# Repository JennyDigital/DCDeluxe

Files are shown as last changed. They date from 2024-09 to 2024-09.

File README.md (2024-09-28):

## It's a door chime board, but programmable.

It can literally sound however you want, but the source-code (unfinished) is provided to get you up-and-runninng.

Have you wondered why there's four DIP switches?.. Coming soon:  A melody playing feature!

...also, let me apologise for the ugly appearance of the CubeMX generated portions of the code, the tool generates ugly code and re-generates it with each re-generated change.  You can tidy it, but it'll just go back to ugly each time.

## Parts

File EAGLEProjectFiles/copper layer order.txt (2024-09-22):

Order of copper layers.
=======================

cmp is the top copper layer.
L2 is the upper inner layer.
L15 is he lower inner layer.
sol is the bottom layer.

Also, the PCB is designed with two prepegs separated by one core, thus placing cmp and L2 very close to each other.  This is inentional.

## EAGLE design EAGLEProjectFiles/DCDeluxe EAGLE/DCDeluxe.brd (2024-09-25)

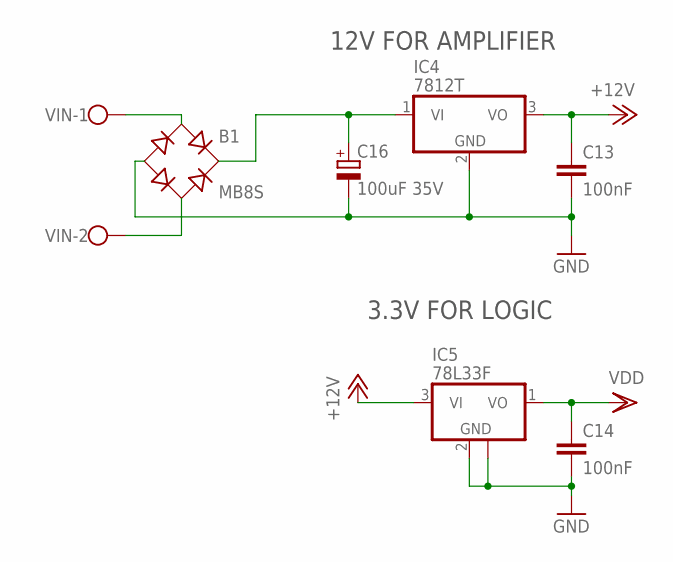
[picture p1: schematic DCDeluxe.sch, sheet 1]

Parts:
B1: MB8S; SOIC-4
C13, C14: 100nF; C0603
C16: 100uF 35V; 153CLV-0807
IC4: 7812T; TO220H
IC5: 78L33F; SOT89
VIN: W237-102

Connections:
+12V: C13.1, IC4.3 (VO), IC5.3 (VI); also elsewhere on the board
GND: B1.-, C13.2, C14.2, C16.-, IC4.2 (GND), IC5.2 (GND), IC5.2@1 (GND); also elsewhere on the board
VDD: C14.1, IC5.1 (VO); also elsewhere on the board
VIN1: B1.~1 (AC1), VIN.1; also elsewhere on the board
VIN2: B1.~2 (AC2), VIN.2; also elsewhere on the board
VIN+: B1.+, C16.+, IC4.1 (VI)

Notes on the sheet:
12V FOR AMPLIFIER
3.3V FOR LOGIC

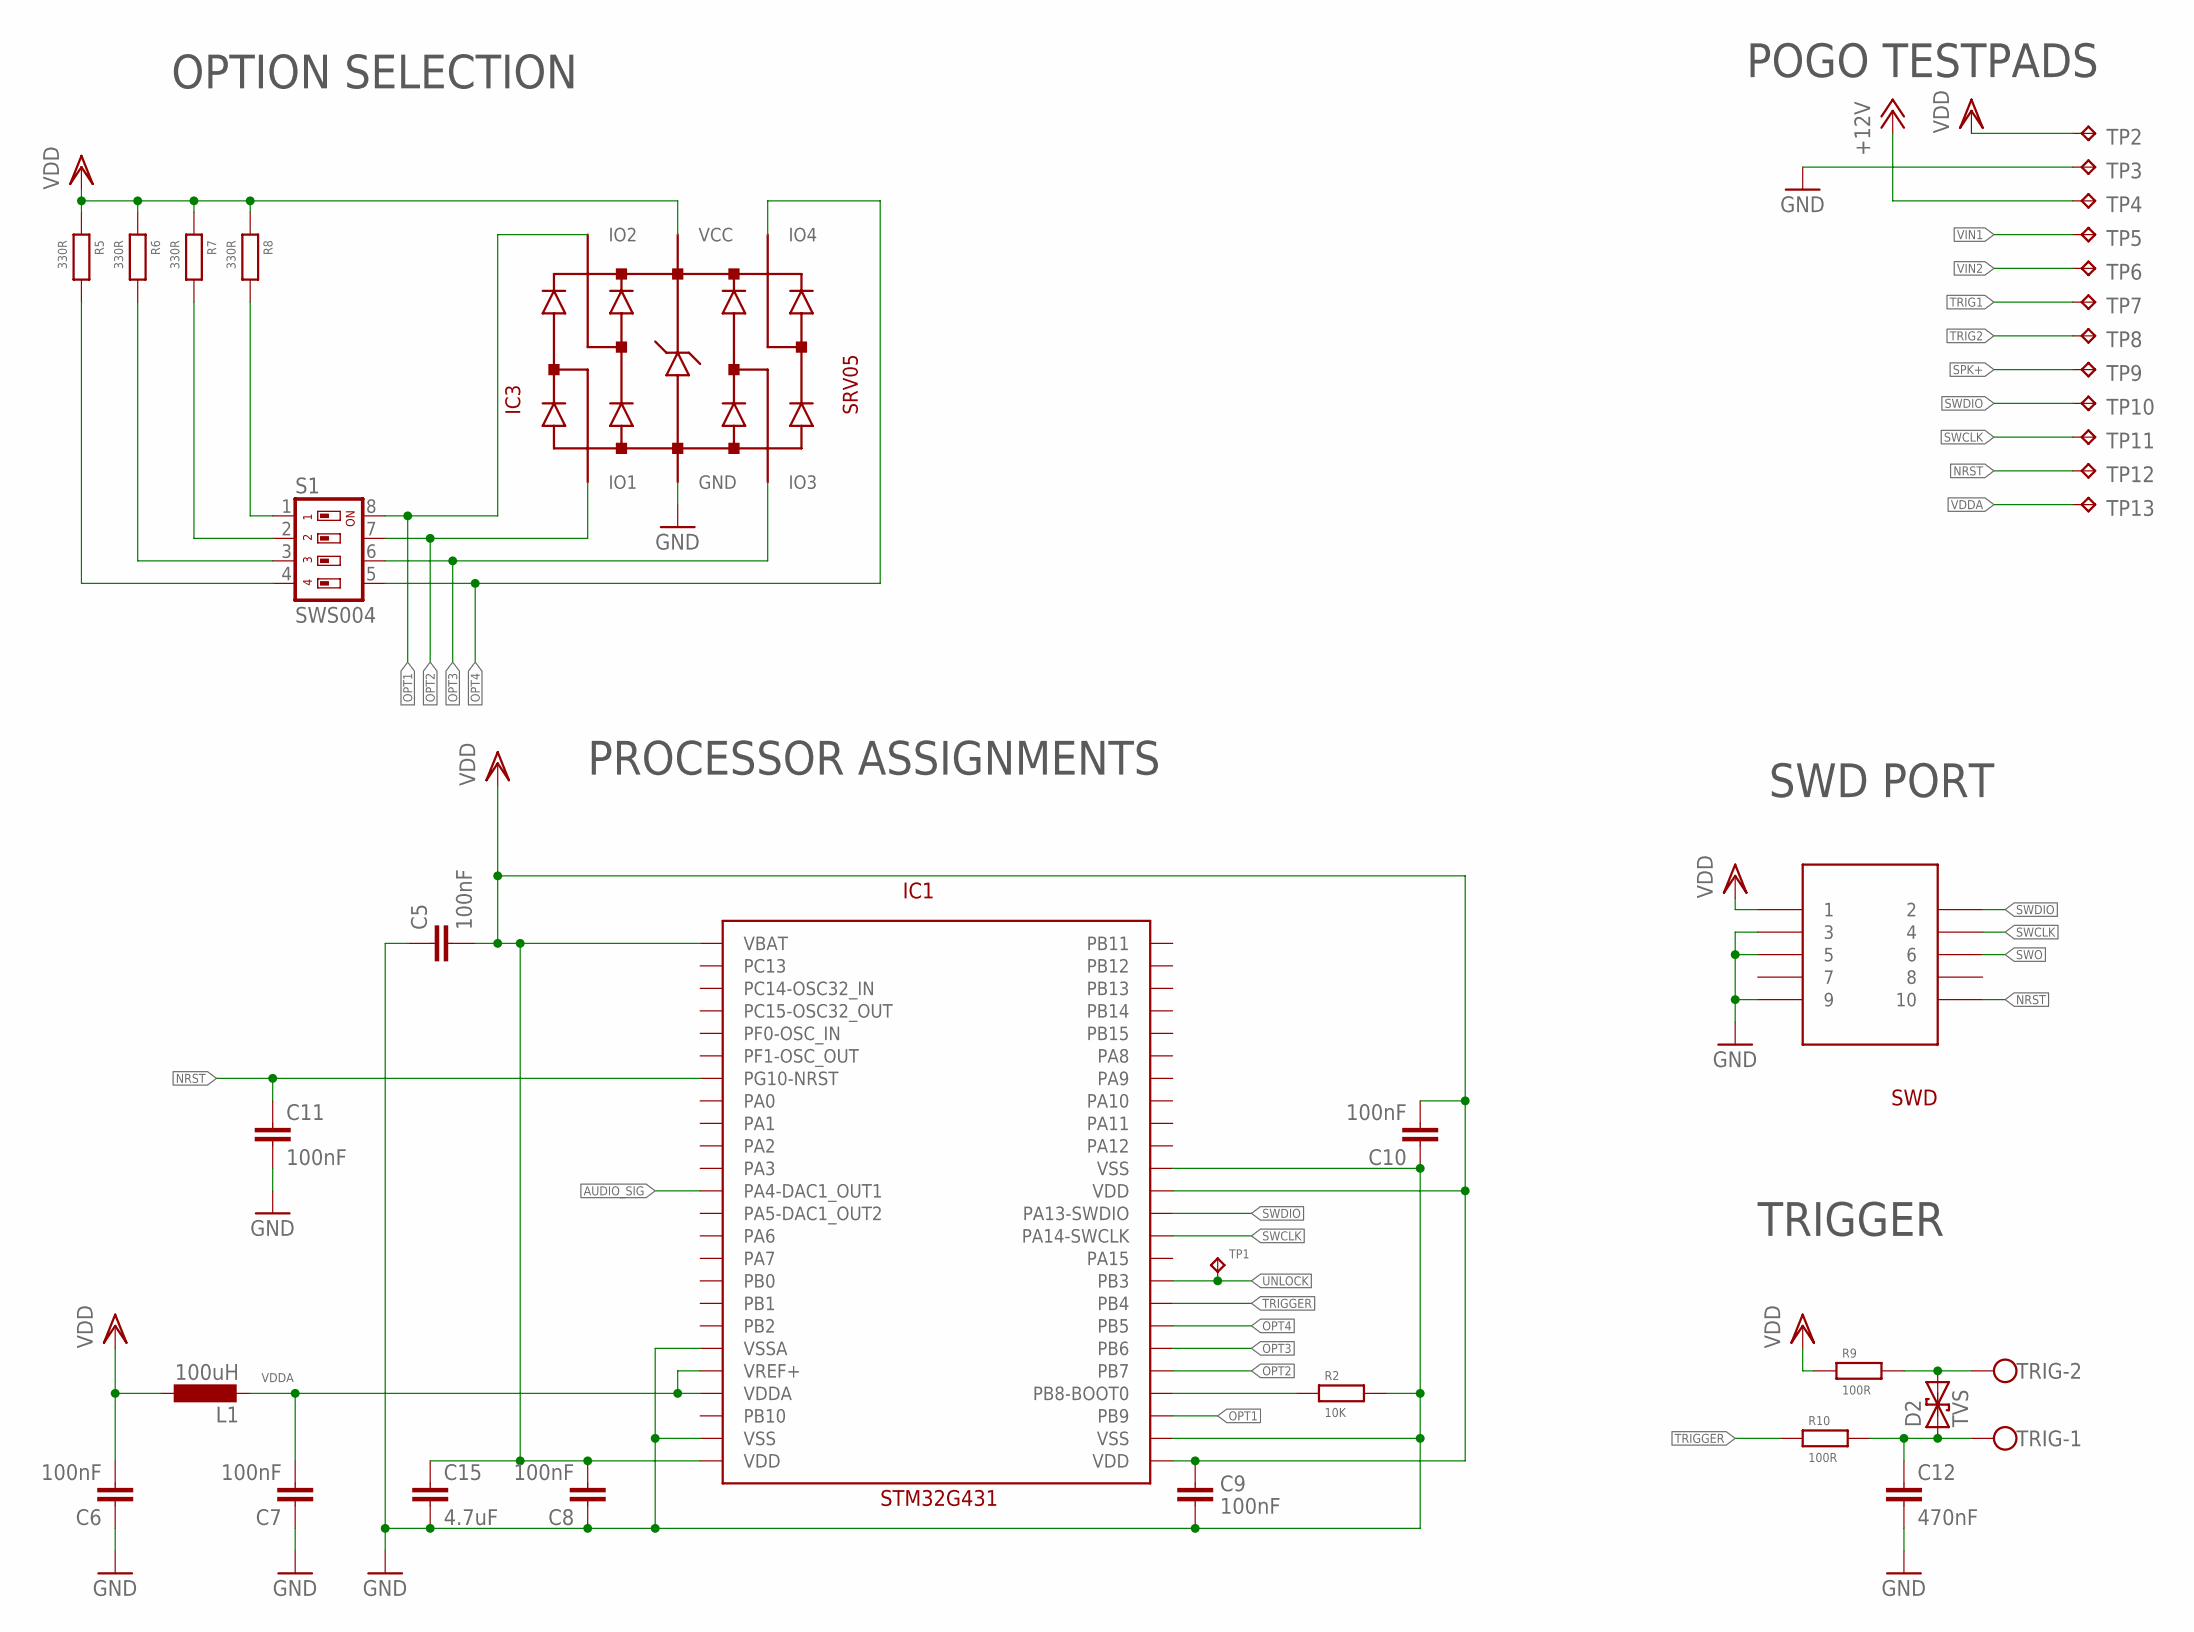
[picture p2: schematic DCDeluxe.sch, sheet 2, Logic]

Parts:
C5, C6, C7, C8, C9, C10, C11: 100nF; C0603
C12: 470nF; C0603
C15: 4.7uF; C0603
D2: TVS; SMA-DIODE
IC1: STM32G431; TQFP48
IC3: SRV05; TSOP-6
L1: 100uH; L3225M
R2: 10K; R0603
R5, R6, R7, R8: 330R; R0603
R9, R10: 100R; R0603
S1: SWS004; SMS-004
SWD: FTSH-105-01; FTSH-105-01-XXX-DV-K
TP1: TPTP12R; TP12R
TP2, TP3, TP4, TP5, TP6, TP7, TP8, TP9, TP10, TP11, TP12, TP13: TPTP20R; TP20R
TRIG: W237-102

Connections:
+12V: TP4.TP; also elsewhere on the board
AUDIO_SIG: IC1.PA4-DAC1_OUT1; also elsewhere on the board
BOOT0: IC1.PB8-BOOT0, R2.1
GND: C5.1, C6.1, C7.1, C8.1, C9.1, C10.1, C11.2, C12.2, C15.2, IC1.VSS@23 (VSS), IC1.VSS@35 (VSS), IC1.VSS@47 (VSS), IC1.VSSA, IC3.GND, R2.2, SWD.3, SWD.5, SWD.9, TP3.TP; also elsewhere on the board
unnamed: R8.2, S1.1
unnamed: R7.2, S1.2
unnamed: R6.2, S1.3
unnamed: R5.2, S1.4
NRST: C11.1, IC1.PG10-NRST, SWD.10, TP12.TP
OPT1: IC1.PB9, IC3.IO2, S1.8
OPT2: IC1.PB7, IC3.IO1, S1.7
OPT3: IC1.PB6, IC3.IO3, S1.6
OPT4: IC1.PB5, IC3.IO4, S1.5
SPK+: TP9.TP; also elsewhere on the board
SWCLK: IC1.PA14-SWCLK, SWD.4, TP11.TP
SWDIO: IC1.PA13-SWDIO, SWD.2, TP10.TP
SWO: SWD.6
TRIG1: C12.1, D2.A (1), R10.2, TP7.TP, TRIG.1
TRIG2: D2.C (2), R9.2, TP8.TP, TRIG.2
TRIGGER: IC1.PB4, R10.1
UNLOCK: IC1.PB3, TP1.TP
VDD: C5.2, C6.2, C8.2, C9.2, C10.2, C15.1, IC1.VBAT, IC1.VDD@24 (VDD), IC1.VDD@36 (VDD), IC1.VDD@48 (VDD), IC3.VCC, L1.1, R5.1, R6.1, R7.1, R8.1, R9.1, SWD.1, TP2.TP; also elsewhere on the board
VDDA: C7.2, IC1.VDDA, IC1.VREF+, L1.2, TP13.TP
VIN1: TP5.TP; also elsewhere on the board
VIN2: TP6.TP; also elsewhere on the board

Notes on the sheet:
OPTION SELECTION
PROCESSOR ASSIGNMENTS
TRIGGER
SWD PORT
POGO TESTPADS

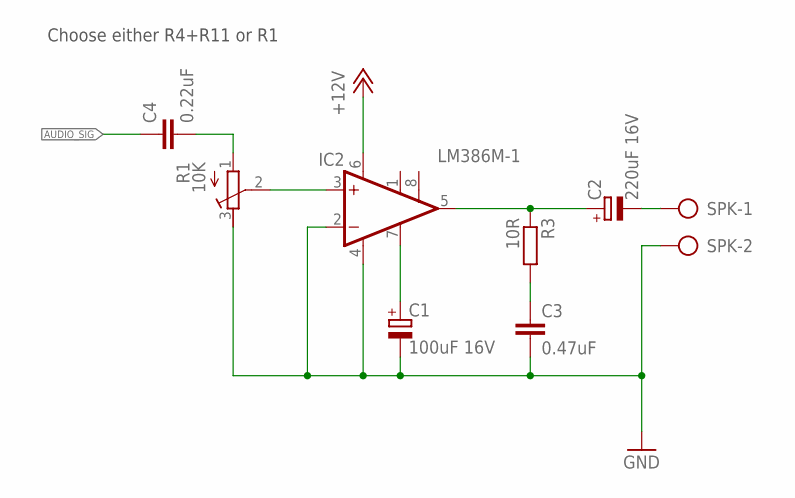
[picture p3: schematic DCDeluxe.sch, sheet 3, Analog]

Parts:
C1: 100uF 16V; 153CLV-0605
C2: 220uF 16V; 153CLV-0605
C3: 0.47uF; C0603
C4: 0.22uF; C0603
IC2: LM386M-1; SO08
R1: 10K; RTRIM3339P
R3: 10R; R0805
SPK: W237-102

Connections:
+12V: IC2.6 (VS); also elsewhere on the board
AUDIO_SIG: C4.1; also elsewhere on the board
GND: C1.-, C3.2, IC2.2 (-IN), IC2.4 (GND), R1.3 (A), SPK.2; also elsewhere on the board
unnamed: IC2.3 (+IN), R1.2 (S)
unnamed: C2.+, IC2.5 (OUT), R3.1
unnamed: C3.1, R3.2
unnamed: C4.2, R1.1 (E)
unnamed: C1.+, IC2.7 (BYPASS)
SPK+: C2.-, SPK.1; also elsewhere on the board

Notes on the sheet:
Choose either R4+R11 or R1

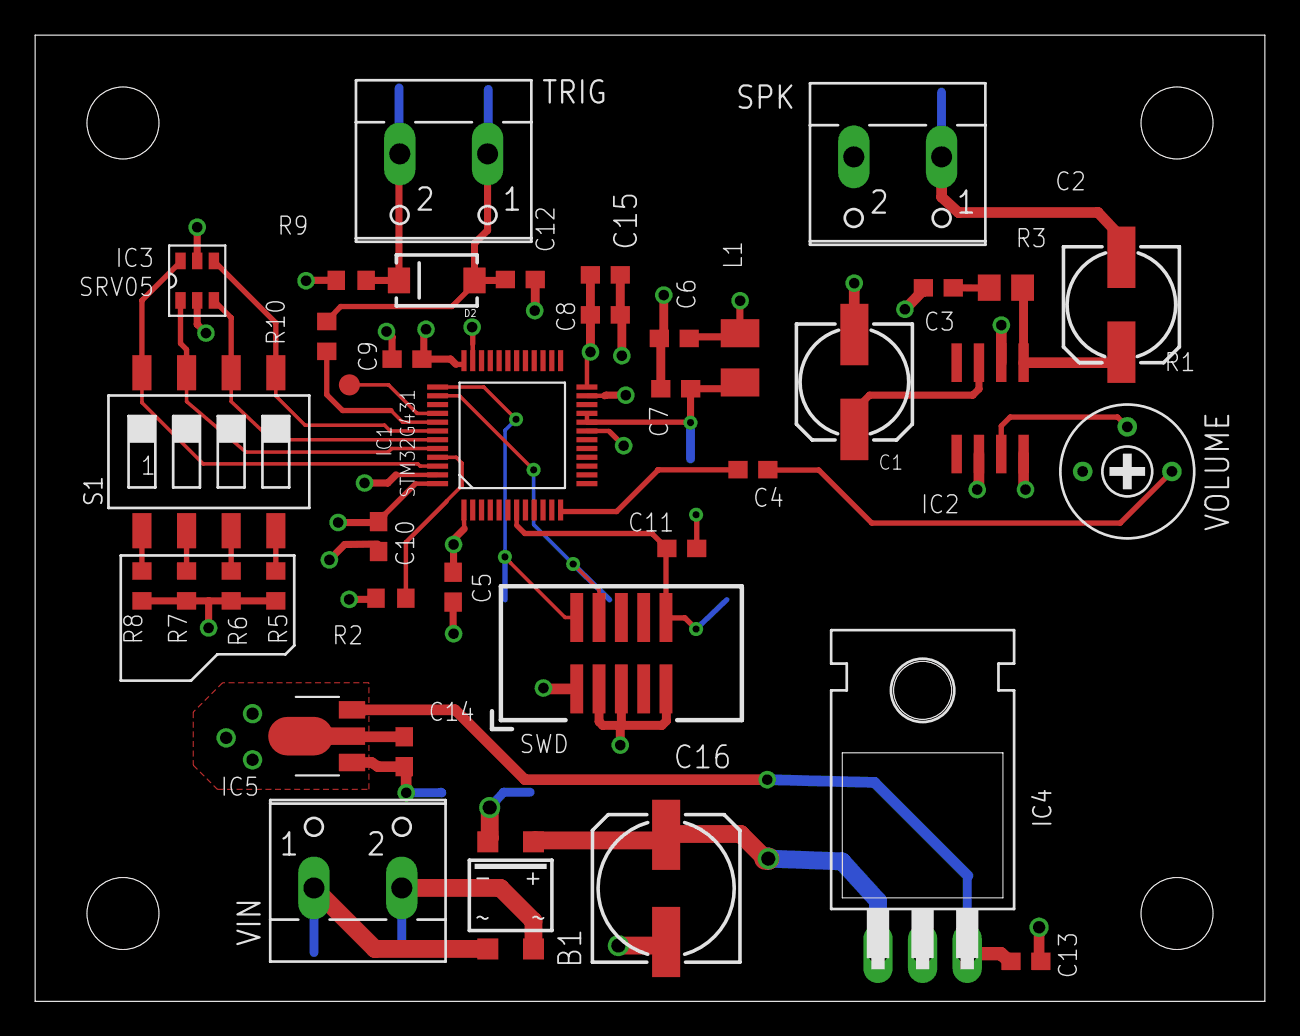
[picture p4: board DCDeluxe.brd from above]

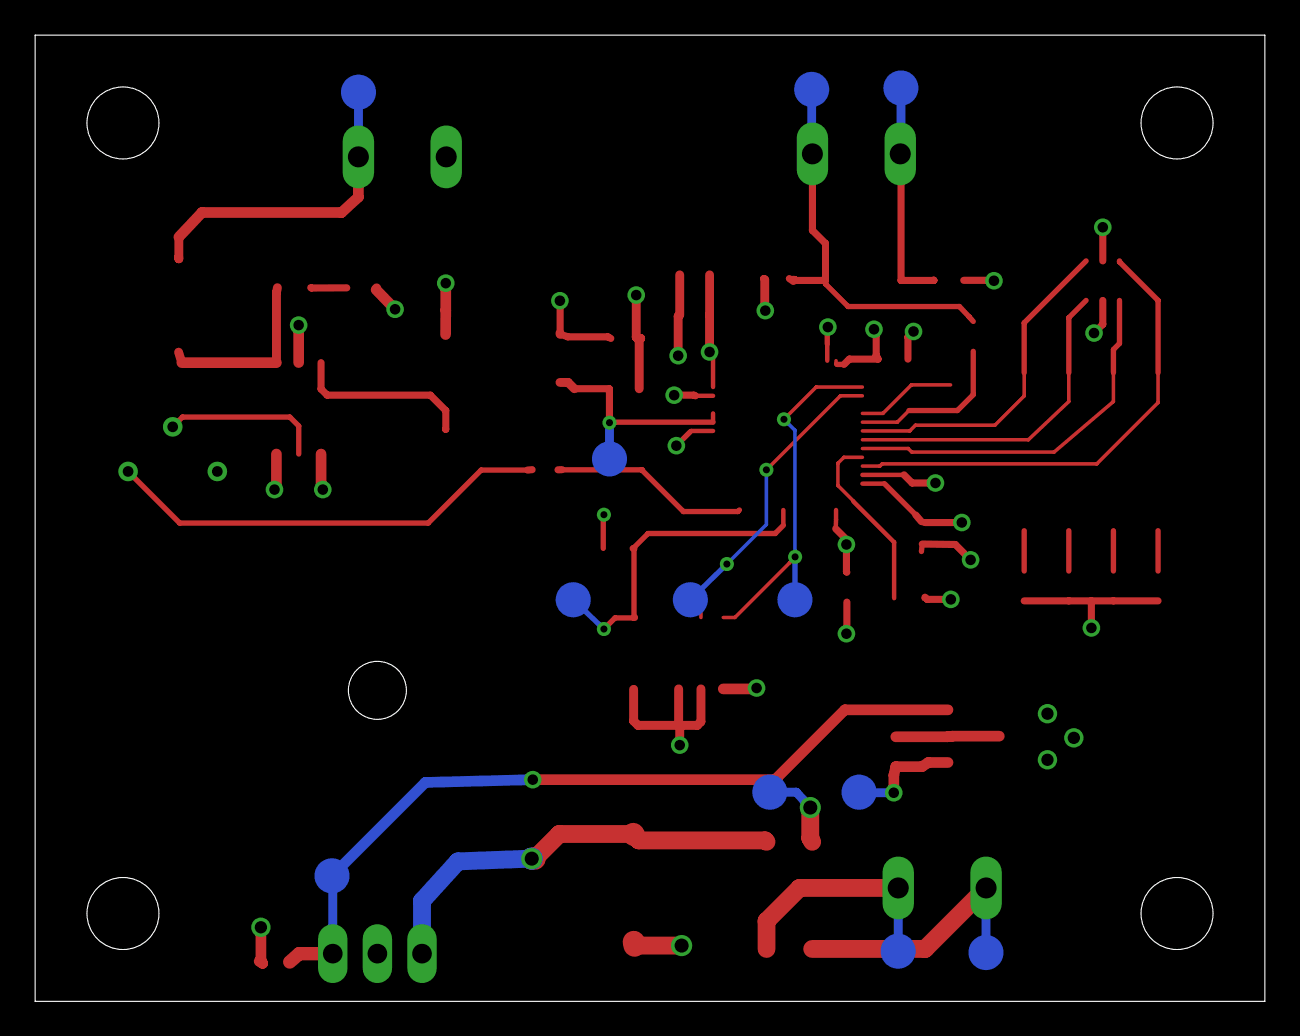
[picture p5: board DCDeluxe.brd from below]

Board: 4 copper layers, 70.0 x 55.0 mm, 51 parts (12 on the bottom side), 30 nets.

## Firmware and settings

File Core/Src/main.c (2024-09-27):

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
/* Includes ------------------------------------------------------------------*/
#include "main.h"
#include "dac.h"
#include "tim.h"
#include "gpio.h"

/* USER CODE BEGIN Includes */
#include "configuration.h"
#include "notes.h"
#include "scores.h"

/* USER CODE END Includes */

/* USER CODE BEGIN PD */

#define WAVETABLE_SZ  16384U
#define SAMPLE_FREQ   ( 150000000.0 / 15.0 / 120.0 )

/* USER CODE END PD */


/* USER CODE BEGIN PV */

// The instantaneous wave state.
            uint16_t        wv                    = 2048;

// The instantaneous phase of each wave.  This is an example of phase accumulators.
volatile    uint16_t        ph1                   = 0,
                            ph2                   = 0,
                            ph3                   = 0;

// Decay rate in steps for each wave's volume.  Higher values mean faster decay.
volatile    uint16_t        note_dec_step         = DECAY_COUNTS;

// Each channel has an associated volume, this is where the current volume is stored.
volatile    int16_t         amp1                  = 0,
                            amp2                  = 0,
                            amp3                  = 0;

// Engine is either playing or has completed.  This is the flag.
            uint8_t         playing               = 0;

// DIP switch option value variable.
            uint8_t         option;

// Master volume divider.  Required to avoid clipping. Amplifier overdrive IS allowed,
// ..but you may not like how it sounds.
            float           mvol_divider;

// phase accumulator steps.  Higher means higher frequencies.  It should be noted that
// there are limited samples available and too big  step won't sound nice.
//
// Very high frequecies are possible!
            uint16_t        ph1_step              = PH1_STEP_DEFAULT,
                            ph2_step              = PH2_STEP_DEFAULT,
                            ph3_step              = PH3_STEP_DEFAULT;

// per-channel drop rates for volume (presets applied)
//
            uint8_t         droprate_ch1          = DROP_RATE,
                            droprate_ch2          = DROP_RATE,
                            droprate_ch3          = DROP_RATE;

// one wants to know when an event should happen, and I don't want a full OS just for this
// therefore there is are simple counters and flag.
volatile    uint32_t        systick_counter       = 0,
                            event_delay           = 0;
volatile    uint8_t         systick_timeout       = 0;

// The wave array is stored as a const int16_t in wave.h, included here.
#include "wave.h"

// Debug variable(s)
#ifdef PEAK_CAPTURE
            uint16_t        peak = 2048;
#endif


/* USER CODE END PV */


void SystemClock_Config(void);

/* USER CODE BEGIN PFP */

__weak  void      eventTimoutCallback           ( void );
        void      HAL_IncTick                   ( void );
        void      HAL_TIM_PeriodElapsedCallback ( TIM_HandleTypeDef *htim );
        void      StartTimer                    ( void );
        uint8_t   readOption                    ( void );
        void      shiftToDACCenter              ( void );
        void      playNote                      ( uint8_t ch,
                                                  float   freq_hz,
                                                  uint8_t dec_rate,
                                                  uint16_t ch_vol
                                                );
        uint16_t  bpm_to_ms                     ( uint16_t bpm );
        void      playScore                     ( float * sc_to_play );

/* USER CODE END PFP */

/**
  * @brief  The application entry point.
  * @retval int
  *
  * Note: there are variables you might like to experiment with like mvol_divider
  * given the great variety of speakers and this boards ability to overdrive the
  * amplifier (at least for now).
  */
int main(void)
{

  /* MCU Configuration--------------------------------------------------------*/

  /* Reset of all peripherals, Initializes the Flash interface and the Systick. */
  HAL_Init();

  /* Configure the system clock */
  SystemClock_Config();

  /* Initialize all configured peripherals */
  MX_GPIO_Init();
  MX_DAC1_Init();
  MX_TIM3_Init();

  /* USER CODE BEGIN 2 */

  HAL_DAC_SetValue( &hdac1, DAC_CHANNEL_1, DAC_ALIGN_12B_R, 2048 );
  HAL_DAC_MspInit( &hdac1 );
  HAL_DAC_Start( &hdac1, DAC_CHANNEL_1 );

  /* USER CODE END 2 */

  /* Infinite loop */
  /* USER CODE BEGIN WHILE */
  while (1)
  {
    /* USER CODE END WHILE */

    /* USER CODE BEGIN 3 */

    // Get option selection.
    //
    option = readOption();

    StartTimer();

    switch( option )
    {
    case 0:                 // Single note
      mvol_divider = 2.25;

      playNote( 1,  nE5 , 2, 1024 );
      break;

    case 1:                 // Two notes descending
      mvol_divider = 2.25;

      playNote( 1, nE5, 2, 1024 );
      HAL_Delay( 680 );
      playNote( 2, nC5, 2, 1024 );
      break;

    case 2:                 // Tri-tone descending
      mvol_divider = 2.25;

      playNote( 1, nE5, 2, 1024 );
      HAL_Delay( 680 );
      playNote( 2, nC5, 2, 1024 );
      HAL_Delay( 680 );
      playNote( 3, nG4, 2, 1024 );
      break;

    case 3:                 // Tri-tone ascending
      mvol_divider = 2.25;

      playNote( 1, nG4, 2, 1024 );
      HAL_Delay( 680 );
      playNote( 2, nC5, 2, 1024 );
      HAL_Delay( 680 );
      playNote( 3, nE5, 2, 1024 );
      break;

    case 4:                 // Musical score 1
      mvol_divider = 2.5;

      playScore( (float *) scale4 );
      break;
    }
    // Wait for end.
    //
    while( amp1 + amp2 + amp3 );
    playing = 0;

    // Reset DAC
    //
    shiftToDACCenter();

#ifndef  TEST_CYCLING_SET
    // Wait for button to be pressed and released
    //
    // The system is also reset, to prevent minor soft errors from accumulating.  This is after all left on
    // for possibly years at a time.  Note also that we don't use that solution in test cycling or debug mode.
    //
    while( !HAL_GPIO_ReadPin( TRIGGER_GPIO_Port, TRIGGER_Pin ) );
#ifndef DEBUG_MODE
    HAL_NVIC_SystemReset();
#endif
#endif

    // Reset the phase accumulators, only necessary in DEBUG_MODE
    //
    ph1 = ph2 = ph3 = 0;
  }

  /* USER CODE END 3 */
}

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
/* USER CODE BEGIN 4 */

/** Event delay callback function.
  *
  */
__weak void eventTimoutCallback( void )
{

}


/** Updates the uwTick variable and updates the systick_counter if not already 0.
  *
  * Overrides the '__weak' version in the HAL.
  *
  * @param none
  * @retval none
  */
void HAL_IncTick(void)
{
  uwTick += uwTickFreq;

  if( systick_counter ) systick_counter--;
  if( event_delay ) event_delay--;
  
  if( !systick_counter )
  {
    // Handle volume decay
    //
    if( amp1 ) amp1 -= droprate_ch1;
    if( amp2 ) amp2 -= droprate_ch2;
    if( amp3 ) amp3 -= droprate_ch3;
    if( amp1 <= CUTOFF_POINT )  amp1 = 0;
    if( amp2 <= CUTOFF_POINT )  amp2 = 0;
    if( amp3 <= CUTOFF_POINT )  amp3 = 0;
    systick_timeout = 1;
    systick_counter = note_dec_step; 
  }  

  if( !event_delay )
  {
      eventTimoutCallback();
  }
}


/** Callback servicing timer interrupts. Overrides the HAL '__weak' version.
  *
  * Only handles interrupts from timer 3 at present, but addind support
  * for other timers is trivial.
  *
  * @param *htim
  * @retval none
  */
void HAL_TIM_PeriodElapsedCallback(TIM_HandleTypeDef *htim)
{
  /* Prevent unused argument(s) compilation warning */
  UNUSED(htim);
  HAL_DAC_SetValue( &hdac1, DAC_CHANNEL_1, DAC_ALIGN_12B_R, wv );
  if( htim !=&htim3 ) return;

   if( playing )
    {
      ph1 += ph1_step;        // Increment phase accumulator for note 1
      ph1 %= WAVETABLE_SZ;

      ph2 += ph2_step;        // Increment phase accumulator for note 2
      ph2 %= WAVETABLE_SZ;

      ph3 += ph3_step;        // Increment phase accumulator for note 3
      ph3 %= WAVETABLE_SZ;

// Below is a complex mess of casting to attempt to improve the audio.
// ...this may be misguided!
      wv = (int16_t)          // Create composite waveform, and yes, the DAC does have a signed
          (                   // mode, but this code should port to other platforms too.
            ( (int32_t) wave[ ph1 ] * amp1 / 1024 ) 
              +
            ( (int32_t) wave[ ph2 ] * amp2 / 1024 )
              +
            ( (int32_t) wave[ ph3 ] * amp3  / 1024 )
          ) / 4 / mvol_divider + 2048;

#ifdef PEAK_CAPTURE
      if( wv > peak ) peak = wv;
#endif
    }
}


/** Starts both the timer, and interrupts from it.
  *
  * @param: none
  * @retval: none
  */
void StartTimer( void )
{
  HAL_TIM_Base_Start_IT( &htim3 );
  HAL_TIM_Base_Start( &htim3 );
}


/** Reads the option switches
  *
  * @param none
  * @retval option value 0..15.
  */
uint8_t readOption( void )
{
  uint8_t opt_read = 0;

  opt_read  = HAL_GPIO_ReadPin( OPT1_GPIO_Port, OPT1_Pin );
  opt_read |= HAL_GPIO_ReadPin( OPT2_GPIO_Port, OPT2_Pin ) << 1;
  opt_read |= HAL_GPIO_ReadPin( OPT3_GPIO_Port, OPT3_Pin ) << 2;
  opt_read |= HAL_GPIO_ReadPin( OPT4_GPIO_Port, OPT4_Pin ) << 3;

  return opt_read;
}


/** Softly move to centere point gracefully.  This avoids pops.
  *
  * @param none
  * @retval none
  *
  */
  void shiftToDACCenter( void )
  {
    char dir = 0;

    if( wv < 2048 ) dir = 1;
    if( wv > 2048 ) dir = -1;
    if( wv == 2048 ) return;

    for( ; wv != 2048; )
    {
      if( dir == 1 ) wv++;
      else wv--;

      HAL_DAC_SetValue( &hdac1, DAC_CHANNEL_1, DAC_ALIGN_12B_R, wv );
    }
  }

/** Play a note
  *
  * @param ch:        the channel to play.
  * @param freq_hz:   The frequency of the note.
  * @param dec_rate:  Decay rate of the note.
  * @param ch_volume: Volume of note at initial strike.
  * @retval none.
  */
void    playNote( uint8_t ch,
                  float freq_hz,
                  uint8_t dec_rate,
                  uint16_t ch_vol
                )
{
  uint16_t ph_step;

  playing = 1;
  ph_step = freq_hz / ( SAMPLE_FREQ / WAVETABLE_SZ );

#ifdef PRINT_SCORE
  debug_printf( "%u, %f, %u\n\r", ch, freq_hz, ch_vol );
#endif
  switch( ch )
  {
    case 1:   // Channel 1
      ph1_step = ph_step;
      ph1 = 0;
      droprate_ch1 = dec_rate;
      amp1 = ch_vol;
    break;

    case 2:   // Channel 2
      ph2_step = ph_step;
      ph2 = 0;
      droprate_ch2 = dec_rate;
      amp2 = ch_vol;
    break;

    case 3:   // Channel 3
      ph3_step = ph_step;
      ph3=0;
      droprate_ch3 = dec_rate;
      amp3 = ch_vol;
    break;
  }
}

/** BPM to ms conversion function
  *
  * @param  bpm
  * @retval ms
  */
uint16_t bpm_to_ms( uint16_t bpm )
{
  #define ONE_MINUTE 60000U     // 1 minute in ms

  return ONE_MINUTE / bpm;
}

void playScore( float *sc_to_play )
{
  uint16_t  score_pointer = 1;
  int beat = bpm_to_ms( sc_to_play[ 1 ] );  // notes per bar = 4
  uint8_t droprate = sc_to_play[2];

  mvol_divider = sc_to_play[ 0 ];

  
  while( sc_to_play[ score_pointer * 3 + 1 ] != END_PLAY )
  {
    
    playNote( (uint8_t) sc_to_play[ score_pointer * 3 ],
              sc_to_play[score_pointer * 3 + 1],
              droprate, 1024 );
    HAL_Delay( beat * sc_to_play[ score_pointer * 3 + 2 ] );

    score_pointer++;
  }
}
/* USER CODE END 4 */
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


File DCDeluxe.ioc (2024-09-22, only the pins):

Mcu.UserName=STM32G431C8Tx
PA13.Signal=SYS_JTMS-SWDIO
PA14.Signal=SYS_JTCK-SWCLK
PA4.GPIO_Label=AUDIO
PA4.Signal=COMP_DAC11_group
PB3.GPIO_Label=UNLOCK
PB3.Signal=GPIO_Input
PB4.GPIO_Label=TRIGGER
PB4.Signal=GPIO_Input
PB5.GPIO_Label=OPT4
PB5.Signal=GPIO_Input
PB6.GPIO_Label=OPT3
PB6.Signal=GPIO_Input
PB7.GPIO_Label=OPT2
PB7.Signal=GPIO_Input
PB9.GPIO_Label=OPT1
PB9.Signal=GPIO_Input

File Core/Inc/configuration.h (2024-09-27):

/*  DCDeluxe. A door chime based on the STM32.
    Copyright (C) 2024 Jennifer Gunn (JennyDigital).

	jennifer.a.gunn@outlook.com

    This software/hardware is free and open; you can redistribute it and/or
    modify it under the terms of the GNU Lesser General Public
    License as published by the Free Software Foundation; either
    version 2.1 of the License, or (at your option) any later version.

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
    You should have received a copy of the GNU Lesser General Public
    License along with this library; if not, write to the Free Software
    Foundation, Inc., 51 Franklin Street, Fifth Floor, Boston, MA  02110-1301
    USA
*/

#ifndef _CONFIGURATION_H
#define _CONFIGURATION_H

#define TRUE    -1
#define FALSE   0


/** User configuration section
  *
  */
//#define TEST_CYCLING_SET
//#define DEBUG_MODE

#ifdef  DEBUG_MODE
// Select as necessary.
//
#define PRINT_SCORE
#define PEAK_CAPTURE
#endif

/** The three pre-defined chime-sets.
  *
  * It should be noted that I have yet to tailor set three to differing values,
  * but you know what you like more than me.
  */

#define CHIMESET_ONE
//#define CHIMESET_TWO
//#define CHIMESET_THREE

#ifdef CHIMESET_ONE
  #define CUTOFF_POINT            10U
  #define DECAY_COUNTS            7U      // Sets the number of systick counts per decay step of the note(s)
  #define SECOND_NOTE_THRESHOLD   680U    // Threshold of bing note to trigger the bong note.
  #define THIRD_NOTE_THRESHOLD    680U    // Threshold of bong note to trigger the dong note.
  #define PH1_STEP_DEFAULT        48      // Offset for phase accumulator 1 (Bing note).
  #define PH2_STEP_DEFAULT        32      // Offset for phase accumulator 2 (Bong note).
  #define PH3_STEP_DEFAULT        24      // Offset for phase accumulator 3 (Dong note).
  #define DROP_RATE               3U      // Rate at which to drop off notes.
  #define NOTE1_VOL               1024U   // Initial volume of note 1
  #define NOTE2_VOL               1024U   // Initial volume of note 2
  #define NOTE3_VOL               1024U   // Initial volume of note 3
#endif

#ifdef CHIMESET_TWO
  #define CUTOFF_POINT            10U
  #define DECAY_COUNTS            3U      // Sets the number of systick counts per decay step of the note(s)
  #define SECOND_NOTE_THRESHOLD   710U    // Threshold of bing note to trigger the bong note.
  #define THIRD_NOTE_THRESHOLD    710U    // Threshold of bong note to trigger the dong note.
  #define PH1_STEP_DEFAULT        60U     // Offset for phase accumulator 1 (Bing note).
  #define PH2_STEP_DEFAULT        50U     // Offset for phase accumulator 2 (Bong note).
  #define PH3_STEP_DEFAULT        40U     // Offset for phase accumulator 3 (Dong note).
  #define DROP_RATE               2U      // Rate at which to drop off notes.
  #define NOTE1_VOL               1024U   // Initial volume of note 1
  #define NOTE2_VOL               1024U   // Initial volume of note 2
  #define NOTE3_VOL               1024U   // Initial volume of note 3
#endif

#ifdef CHIMESET_THREE
  #define CUTOFF_POINT            10U
  #define DECAY_COUNTS            5U      // Sets the number of systick counts per decay step of the note(s)
  #define SECOND_NOTE_THRESHOLD   800U    // Threshold of bing note to trigger the bong note.
  #define THIRD_NOTE_THRESHOLD    800U    // Threshold of bong note to trigger the dong note.
  #define PH1_STEP_DEFAULT        32U     // Offset for phase accumulator 1 (Bing note).
  #define PH2_STEP_DEFAULT        48U     // Offset for phase accumulator 2 (Bong note).
  #define PH3_STEP_DEFAULT        64U     // Offset for phase accumulator 3 (Dong note).
  #define DROP_RATE               2U      // Rate at which to drop off notes.
  #define NOTE1_VOL               1024U   // Initial volume of note 1
  #define NOTE2_VOL               1024U   // Initial volume of note 2
  #define NOTE3_VOL               1024U   // Initial volume of note 3
#endif


#include <stdint.h>

#ifdef DEBUG_MODE
  #include <cross_studio_io.h>
#endif

#endif

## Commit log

2024-09-22 Initial commit.
    [DCDeluxe.brd, DCDeluxe.sch, configuration.h]
2024-09-22 FIX: Tidied up the rubbish to make it more open source friendly
    [configuration.h]
2024-09-22 FIX: Accidentally included an extra #, and also removed some unused variables.
    [configuration.h]
2024-09-22 Added some comments, updated some chimeset data, and removed an unused variable
    [configuration.h]
2024-09-23 FIX: Made adjustments to the code to reduce popping at start and settle the state to midpoint at end
    [main.c]
2024-09-25 FEATURE: Reverse note sequence by setting switch 3
    [configuration.h]
2024-09-25 Twiddled with the notes to my liking, I'm so fickle!
    [configuration.h]
2024-09-25 TWEAKS: Updated PCB layout
    [DCDeluxe.brd, DCDeluxe.sch]
2024-09-26 FIX: Remove warning from wave calculation with explicit cast
    [main.c]
2024-09-27 Got a basic sequencer running with a simple scale. Also refactored for simplicitys sake
    [configuration.h]
2024-09-27 Revert "FIX: Remove warning from wave calculation with explicit cast"
    This reverts commit 02eac132bfddab33ac2fe929af5cb5da98a03053.
    Having merge conflicts. I need to learn more about git!
    [main.c]
2024-09-27 Removed a warning by explicit cast. This was reverted due to a mistake on my part, but is re-fixed now.
    [main.c]
2024-09-27 FIX: Silly bug on my part!
    [configuration.h]
2024-09-27 FIX: Set the starting position of a newly struck note to 2048 (halfway) to reduce start of note clicks.
    FIX: explicitly cast the chosen score array as (float *) to remove warning.
    [configuration.h]

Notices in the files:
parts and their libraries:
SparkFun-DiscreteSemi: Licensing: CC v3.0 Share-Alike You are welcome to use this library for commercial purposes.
